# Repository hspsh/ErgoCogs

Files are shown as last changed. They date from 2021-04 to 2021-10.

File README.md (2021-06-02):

# ErgoCogs - modular ErgoDox for lifelong tinkerers

The idea for this project was born, when a couple of us couldn't decide on which features should our upcoming ErgoDox fork have.

The (conflicting) ideas were:
* Basic teensy with mini-usb
* Anything USB-C based
* Battery - powered bluetooth keyboard
* Custom STM32-based logic with SMD pre-assembly at factory

So why not have it all? The simplest solution is splitting the design into 2 parts. It has many advantages:

* The stupid matrix PCB is also the most expensive, as PCB manufacturers usually charge extra for anything larger than 10x10cm.
* If you get bored with with your basic bitch cherry mx matrix, why not swap it for them crunchy jade kalihs? Maybe just for a weekend? Or maybe sell your old matrix to a fellow hacker!
* The controller PCBs are small, and hence dirt cheap, and this is where most of customisation would take place. Take your time and experiment with wacky knobs and OLED displays until you get your perfect hackertyper experience.

It also has some disadvantages:

* The goldpin connector might be not the most relaiable way to connect 2PCBs. We're yet to check if this concept actually works out. Worst case, both sides may be semi-permanently soldered together with longer pinheaders.

## MatrixCog

This PCB is as dumb as it gets - it's basically an switch matrix routed do the 2x5 + 2x3 goldpin side connectors. It also features some LEDs.

To save some time, I recommend ordering this one with silicon diodes pre-assembled (`.cpl` file is included)

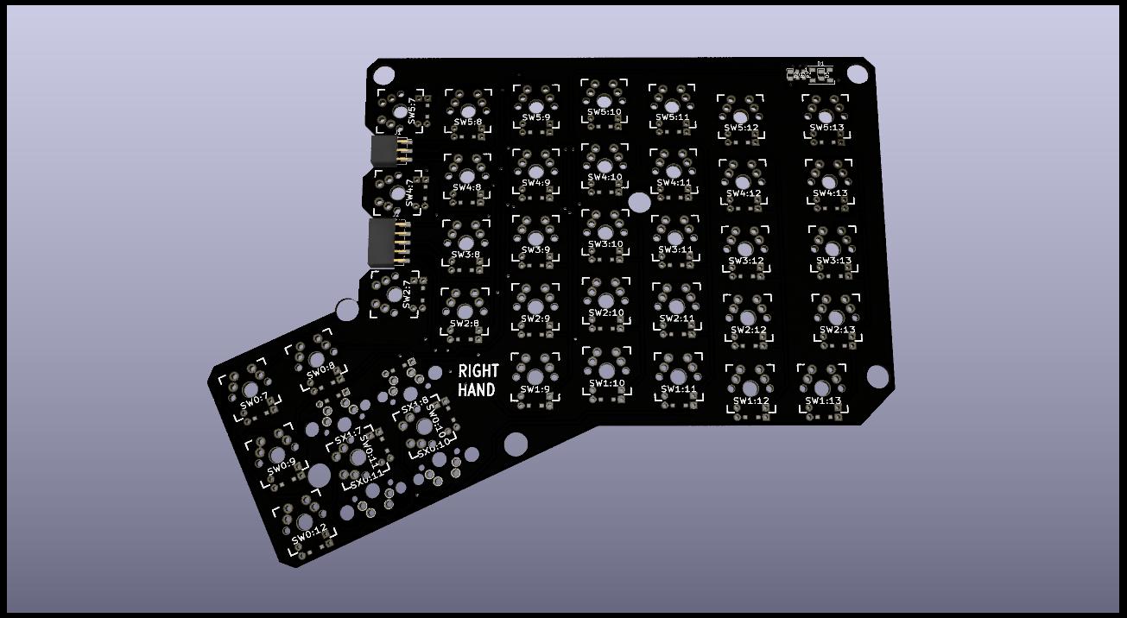
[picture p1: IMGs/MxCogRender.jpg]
Matrix Cog Render


## BrainCogs

Here's when the fun begins. We provide 2 example hemispheres that feature some basic functionalities. You can fork the shit out of this repo and modify these for your own needs.
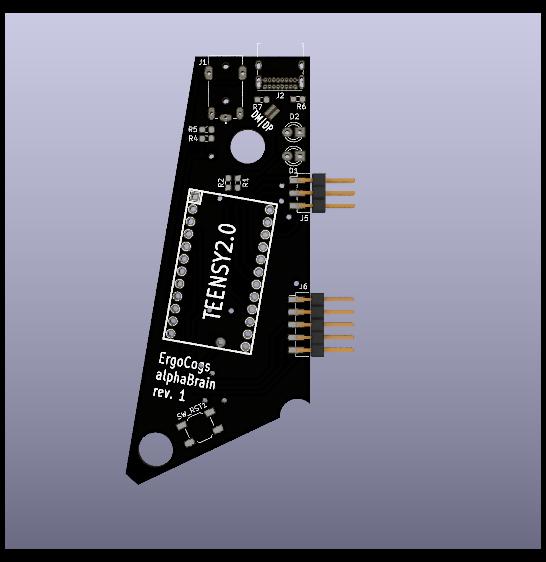
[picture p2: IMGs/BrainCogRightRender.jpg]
Brain Cog right hemisphere render

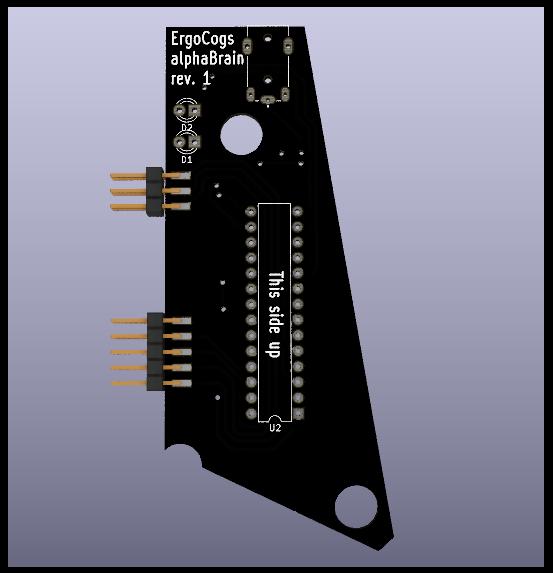
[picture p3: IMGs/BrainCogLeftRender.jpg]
Brain Cog left hemisphere render


## Some pictures

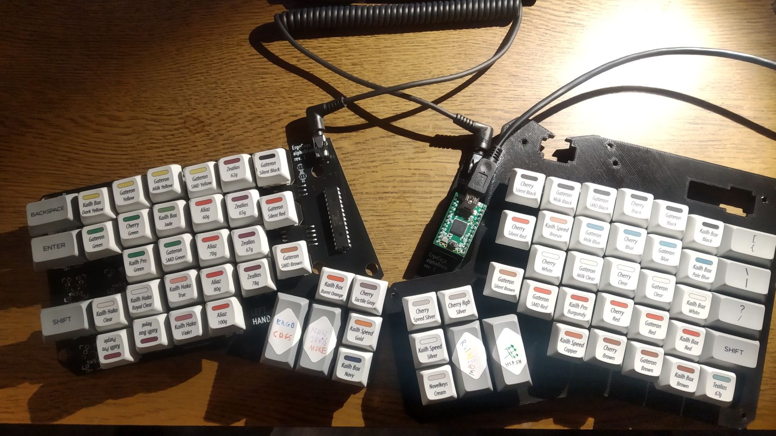
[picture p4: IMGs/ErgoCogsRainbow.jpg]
Prototype ErgoCogs keyboard with switches from a tester


More to come...

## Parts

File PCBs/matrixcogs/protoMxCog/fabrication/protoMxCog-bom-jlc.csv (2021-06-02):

Comment | Designator | Footprint | LCSC Part #
WS2812B RGB LED with integrated controller | D1,D4 | LED_WS2812B_PLCC4_5.0x5.0mm_P3.2mm
D | D1:7,D1:8 | DIODE
LED_R | D2,D3 | LED_0805_2012Metric_Pad1.15x1.40mm_HandSolder
LED_G | D5,D6 | LED_0805_2012Metric_Pad1.15x1.40mm_HandSolder
MECHANICAL | H99 | ErgoDOXmech
Conn_01x06 Generic connector, single row, 01x06, script generated (kicad-library-utils/schlib/autogen/connector/) | J1 | ErgoCogs_sidecon_top
Conn_01x10 Generic connector, single row, 01x10, script generated (kicad-library-utils/schlib/autogen/connector/) | J2 | ErgoCogs_sidecon_bot
470 Resistor, small symbol | R1,R2,R3,R4 | R_0603_1608Metric_Pad0.98x0.95mm_HandSolder
STAB200 | S1,S2 | STAB_PCB940
SW_DIODE | DS1,DS2,DS3,DS4,DS5,DS6,DS7,DS8,DS9,DS10,DS11,DS12,DS13,DS14,DS15,DS16,DS17,DS18,DS19,DS20,DS21,DS22,DS23,DS24,DS25,DS26,DS27,DS28,DS29,DS30,DS31,DS32,DS33,DS34,DS35,DS36,DS37,DS38,DS39,DS40,DS41,DS42 | SOD-123

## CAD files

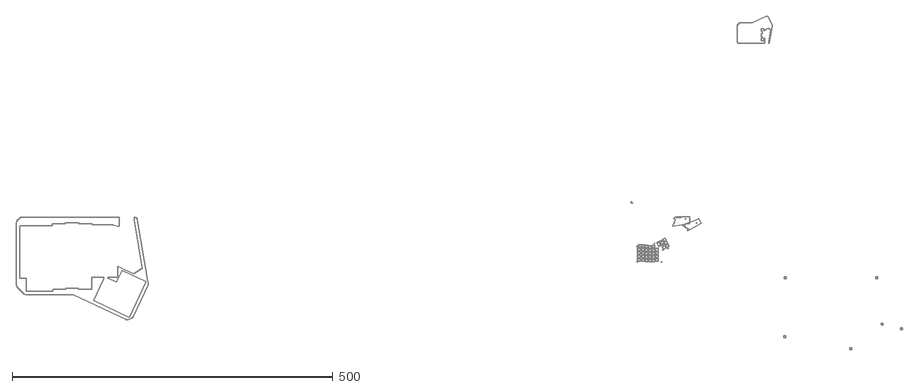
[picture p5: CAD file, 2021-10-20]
GearBoxes/ErgoCogs_integrated/integrated_plate_all.dxf
1380.8 x 520.0

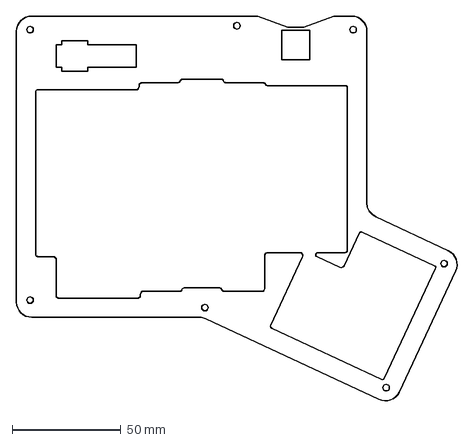
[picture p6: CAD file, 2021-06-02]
GearBoxes/ErgoDOX Acrylic Case - Designed by Litster/Standard/Left/ErgoDOX Case Layer 2 Spacer - Left.dxf
202.8 x 177.8 mm

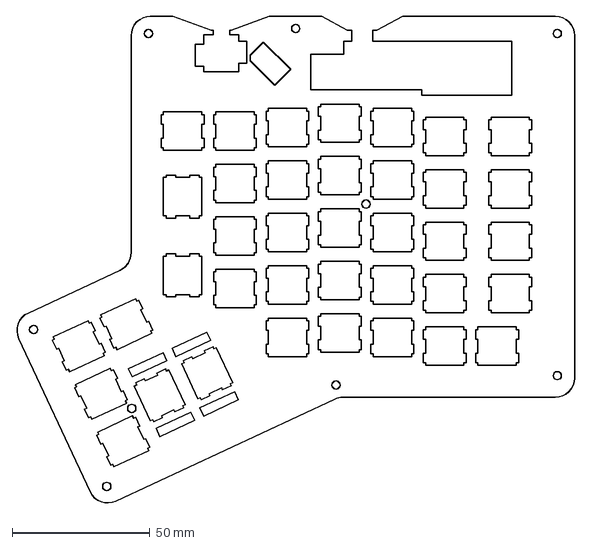
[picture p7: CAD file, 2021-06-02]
GearBoxes/ErgoDOX Acrylic Case - Designed by Litster/Standard/Right/ErgoDOX Case Layer 3 Plate - Right.dxf
202.8 x 177.8 mm

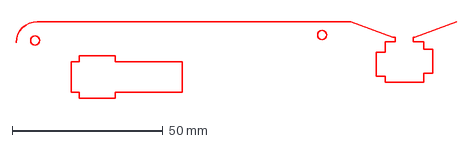
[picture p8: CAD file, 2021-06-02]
GearBoxes/ErgoDOX Acrylic Case - Designed by Litster/with Wrist Rest/Left/test cut.dxf
146.0 x 25.5 mm

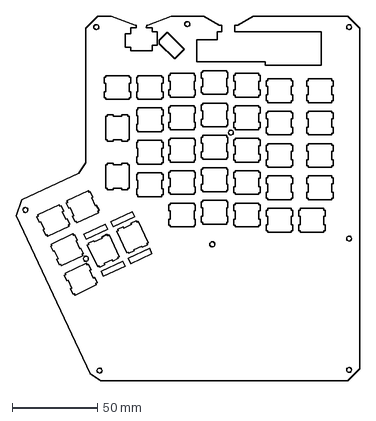
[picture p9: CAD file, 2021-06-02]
GearBoxes/ErgoDOX Acrylic Case - Designed by Litster/with Wrist Rest/Right/ErgoDOX Wrist Rest Case Layer 3 Plate - Right.dxf
202.0 x 214.1 mm

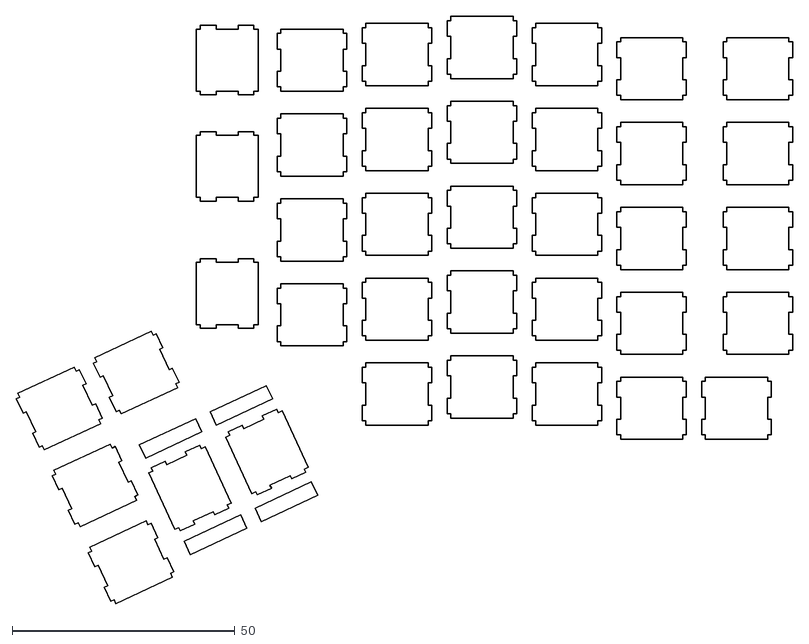
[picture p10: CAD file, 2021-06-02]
PCBs/matrixcogs/protoMxCog/fabrication/protoMxCog-Eco2_User.dxf
174.2 x 131.8

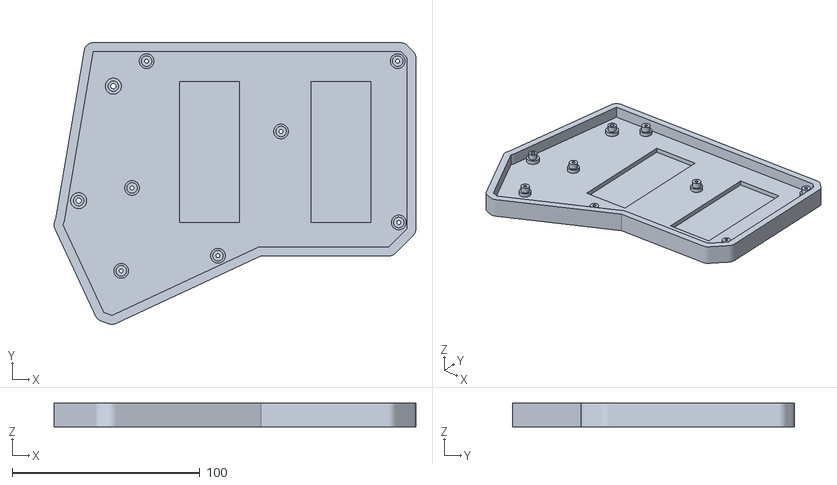
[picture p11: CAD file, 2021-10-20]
GearBoxes/ErgoCogs_integrated/integrated_plate.stl
192.8 x 150.1 x 12.6

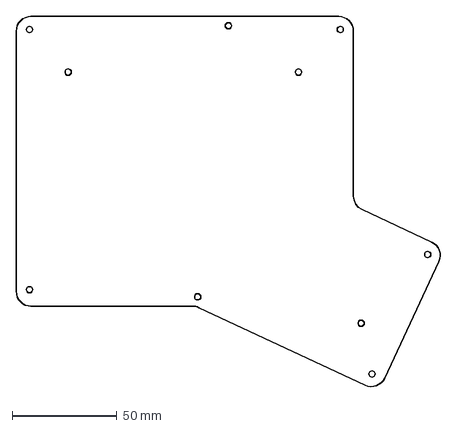
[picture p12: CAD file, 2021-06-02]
GearBoxes/ErgoDOX Acrylic Case - Designed by Litster/Standard/Left/ErgoDOX Case Layer 5 Bottom - Left.dxf
202.8 x 177.8 mm

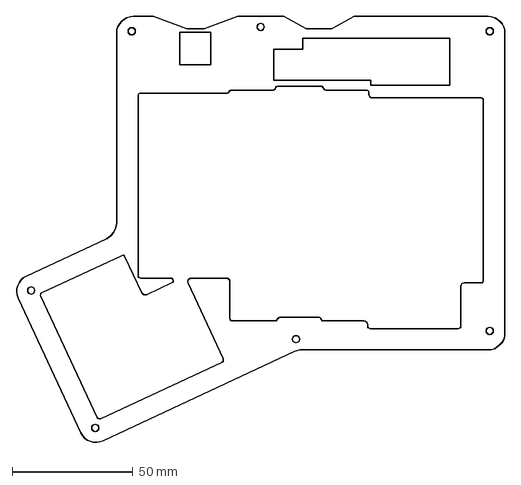
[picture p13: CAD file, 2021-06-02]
GearBoxes/ErgoDOX Acrylic Case - Designed by Litster/Standard/Right/ErgoDOX Case Layer 2 Spacer - Right.dxf
202.8 x 177.8 mm

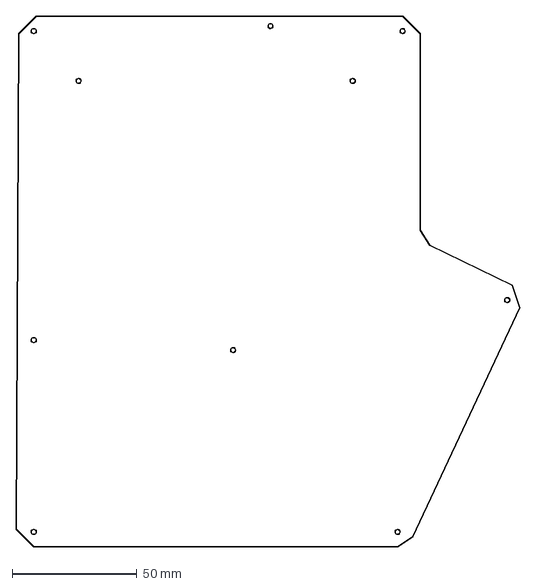
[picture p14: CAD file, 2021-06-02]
GearBoxes/ErgoDOX Acrylic Case - Designed by Litster/with Wrist Rest/Left/ErgoDOX Case Layer 5 Bottom - Left.dxf
202.0 x 213.0 mm

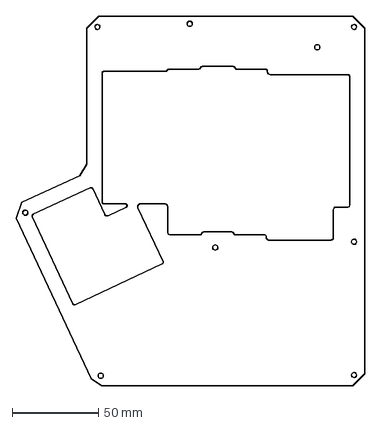
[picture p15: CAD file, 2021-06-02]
GearBoxes/ErgoDOX Acrylic Case - Designed by Litster/with Wrist Rest/Right/ErgoDOX Wrist Rest Case Layer 1 Top - Right.dxf
202.0 x 214.1 mm

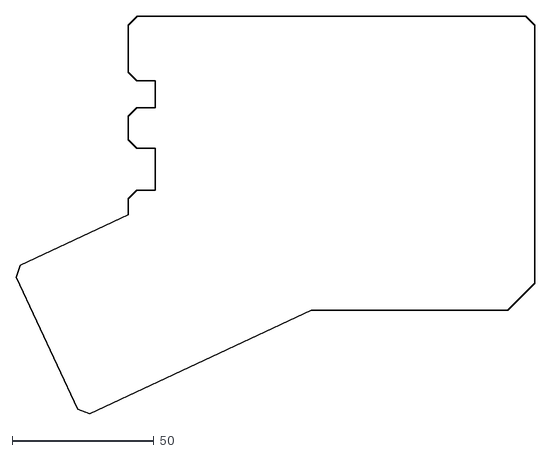
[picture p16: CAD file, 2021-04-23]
PCBs/matrixcogs/protoMxCog/fabrication/protoMxCog-Edge_Cuts.dxf
182.8 x 140.1

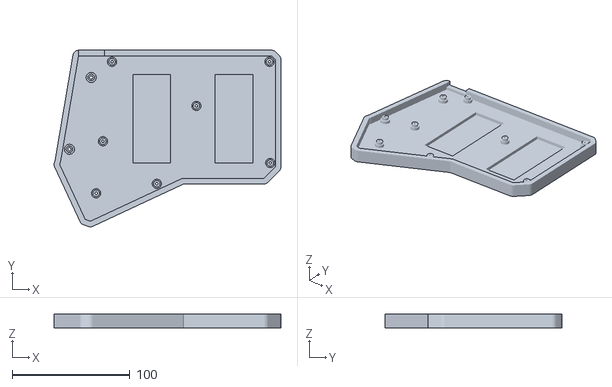
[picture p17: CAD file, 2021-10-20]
GearBoxes/ErgoCogs_integrated/integrated_plate_right.stl
192.8 x 150.1 x 11.6

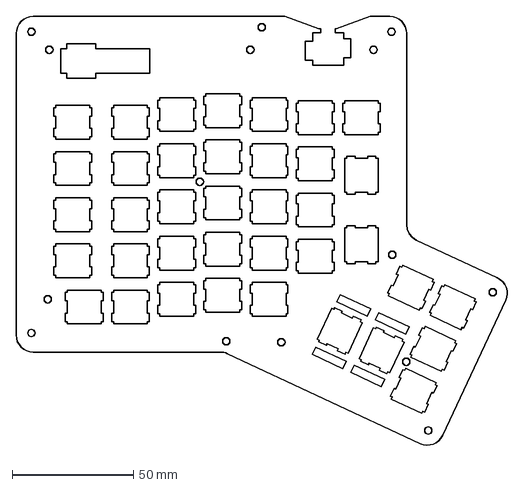
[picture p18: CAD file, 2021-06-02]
GearBoxes/ErgoDOX Acrylic Case - Designed by Litster/Standard/Left/ErgoDOX Case Layer 3 Plate - Left.dxf
202.8 x 177.8 mm

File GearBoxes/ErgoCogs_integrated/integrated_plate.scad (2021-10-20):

plate_h=1.55;
board_h=1.5;
bottom_h=5;
bottom_space=2.5;
side_h=5;

tolerance=0.2;
screw_d=2.3;


actual_hole_d=6;
jack_d=7;

fix_scale=1.0075; // The boards are a bit bigger? My priter uncalibrated ?

weight_h = 3;
weight_x = 32;
weight_y = 75;

$fn=30;

module tray(plate_h=plate_h,bottom_h=bottom_h,side_h=side_h,tolerance=tolerance,outline_file="outer_outline.dxf",sides=true,bottom_space=bottom_space) {

  in_offset = sides ? tolerance : bottom_h ;
  difference(){
    linear_extrude(bottom_h+side_h+plate_h)
      offset(r=bottom_h)
        import(outline_file);
    translate([0,0,bottom_h])
      linear_extrude(bottom_h+side_h+plate_h)
        offset(r=in_offset)
          import(outline_file);    
  }
}

module standoffs(plate_h=plate_h,bottom_h=bottom_h,side_h=side_h,tolerance=tolerance, 
    holes_file="mount_holes.dxf")
{
    linear_extrude(bottom_h+side_h)
        offset(delta=-tolerance/2)
          import(holes_file); // "columns"
    linear_extrude(bottom_h+bottom_space)
        offset(delta=1)
          import(holes_file); // plate rests
}

module holes(
    plate_h=plate_h,
    bottom_h=bottom_h,
    side_h=side_h,
    tolerance=tolerance, 
    delta=-0.4,
    holes_file="mount_holes.dxf")
{
    linear_extrude(bottom_h+side_h+1)
      offset(delta=-(actual_hole_d-screw_d)/2)
        import(holes_file); // screw holes
    linear_extrude(bottom_h)
      offset(delta=delta)
        import(holes_file); // nut hole
}

module bottom(plate_h=plate_h,bottom_h=bottom_h,side_h=side_h,tolerance=tolerance,outline_file="outer_outline.dxf",holes_file="mount_holes.dxf",sides=true,bottom_space=bottom_space) 
{
  brain_offset = [-88.79,-5.7,0];
  difference(){
    union(){
      tray(plate_h,bottom_h=bottom_h,side_h=side_h,tolerance=tolerance,outline_file=outline_file,sides=sides,bottom_space=bottom_space);
      standoffs(plate_h=plate_h,bottom_h=bottom_h,side_h=side_h,tolerance=tolerance, holes_file=holes_file);
      translate(brain_offset) standoffs(plate_h=plate_h,bottom_h=bottom_h,side_h=side_h,tolerance=1, holes_file="brain_holes.dxf");
    }
    holes(plate_h=plate_h,bottom_h=bottom_h,side_h=side_h,tolerance=tolerance, holes_file=holes_file);
    translate(brain_offset) holes(plate_h=plate_h,bottom_h=bottom_h,side_h=side_h, holes_file="brain_holes.dxf");
    // weight slots
    translate([85, -140, bottom_h-weight_h]) cube([weight_x,weight_y,weight_h]);
    translate([155, -140, bottom_h-weight_h]) cube([weight_x,weight_y,weight_h]);
    
    // IO
    translate([39,-60,bottom_h+bottom_space +0])
        cube([22,22,20]);

  }
}


module brain_translate(){
  translate([-88.79,-5.7,0])
    children();
}

module brain_bottom(plate_h=plate_h,bottom_h=bottom_h,side_h=side_h,tolerance=tolerance,outline_file="brain_outline.dxf",holes_file="brain_holes.dxf",sides=true,bottom_space=bottom_space)
{
  brain_translate()
    bottom(plate_h=plate_h,bottom_h=bottom_h,side_h=side_h,tolerance=tolerance,outline_file=outline_file,holes_file=holes_file,sides=sides,bottom_space=bottom_space);
}

module full_bottom(plate_h=plate_h,bottom_h=bottom_h,side_h=side_h,tolerance=tolerance){
//  union(){
//    difference(){
      bottom(plate_h=plate_h,bottom_h=bottom_h,side_h=side_h,tolerance=tolerance);
//      brain_translate()
//        linear_extrude(side_h+2*bottom_h+bottom_space)
//          import("brain_bigger_outline.dxf");
//    }
//  }
}

module plate(plate_h=plate_h) {
  linear_extrude(plate_h)
    import("plate_outline.dxf");
}

module cutouts(plate_h=plate_h) {
linear_extrude(plate_h)
  union(){
    import("plate_cutouts.dxf");  
    // For M3 - check if screw head fits!
    //offset(r=-1.45)
    // For M2.5
    offset(r=-1.67)
    // For M2
    //offset(r=-1.86)
      import("mount_holes.dxf");
  }
}

module plate_with_cutouts(plate_h=plate_h){
  difference(){
    plate(plate_h);
    cutouts(plate_h);
  }
}

module plate_sample(plate_h=plate_h){
  intersection(){
    union(){
      translate([40,-195,0])
        rotate([0,0,25])
          cube([65,42,plate_h]);
      translate([81,-169.5,0])
        cube([130,40,plate_h]);
    }

    plate_with_cutouts(plate_h);
  }
}

module brain_bottom_cartridge(usb=false) {
  slider_w=2;
  slider_l=9;
  slider_gap=0.1;
  difference(){
    union(){
      intersection(){
        brain_bottom();
        brain_translate()
          linear_extrude(side_h+2*bottom_h+bottom_space)
            import("brain_bigger_outline.dxf");
      }
      translate([60,-49-slider_w,bottom_h])
        cube([slider_l,slider_w,bottom_space-tolerance]); // slider rail
    }
    linear_extrude(10)
      offset(delta=1.2)
        import("mount_holes.dxf");
    if(usb)
      translate([40,-80,bottom_h+bottom_space+board_h+0.5])
        cube([20,20,20]);
    translate([41.5,-47.15,bottom_h+side_h-0.5])
      translate([jack_d/2,0,0])
        rotate([90,0,0])
        union(){
          translate([-jack_d/2,0,0])
            cube([jack_d,jack_d,bottom_h]);
          if(usb)
            translate([jack_d/2+2,-jack_d/2+1,0])
              cube([10,10,bottom_h]);
          cylinder(d=jack_d,h=bottom_h);
        }
  }  
}
module all(plate=false,bottom=false,brain=false, right=false, left=false){
  scale([fix_scale,fix_scale,fix_scale]){
      
    if(left){
      if(bottom)
        translate([20,0,0])
          full_bottom();
      if(brain)
        translate([0,0,0])
          brain_bottom_cartridge(usb=true);
      if(plate)
        translate([0,-160,0])
          //sample();
          plate_with_cutouts();

    }
    if(right || !right && !left) // right hand by default
      mirror([1,0,0]){
        if(bottom)
          translate([20,0,0])
            full_bottom();
        if(brain)
          translate([0,0,0])
            brain_bottom_cartridge(usb=false);
        if(plate)
          translate([0,-160,0])
            //sample();
            plate_with_cutouts();

      }  
  }
}

//all(brain=false,bottom=true,plate=false,left=true,right=true);

bottom();

//plate_sample();
//all(bottom=true,left=true,right=true);

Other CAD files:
GearBoxes/ErgoDOX Acrylic Case - Designed by Litster/Standard/Right/ErgoDOX Case Layer 4 Spacer - Right.dxf
GearBoxes/ErgoDOX Acrylic Case - Designed by Litster/with Wrist Rest/Left/ErgoDOX Case Layer 4 Spacer - Left.dxf
GearBoxes/ErgoDOX Acrylic Case - Designed by Litster/with Wrist Rest/Right/ErgoDOX Wrist Rest Case Layer 2 Spacer - Right.dxf
GearBoxes/ErgoCogs_integrated/plate.stl
GearBoxes/ErgoCogs_integrated/plate.scad
GearBoxes/ErgoCogs_integrated/all.stl
GearBoxes/ErgoCogs_integrated/bottom.stl
GearBoxes/ErgoCogs_integrated/brain_bigger_outline.dxf
GearBoxes/ErgoCogs_integrated/brain_bottom.stl
GearBoxes/ErgoCogs_integrated/brain_holes.dxf
GearBoxes/ErgoCogs_integrated/brain_outline.dxf
GearBoxes/ErgoCogs_integrated/mount_holes.dxf
GearBoxes/ErgoCogs_integrated/outer_outline.dxf
GearBoxes/ErgoCogs_integrated/plate_cutouts.dxf
GearBoxes/ErgoCogs_integrated/plate_outline.dxf
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

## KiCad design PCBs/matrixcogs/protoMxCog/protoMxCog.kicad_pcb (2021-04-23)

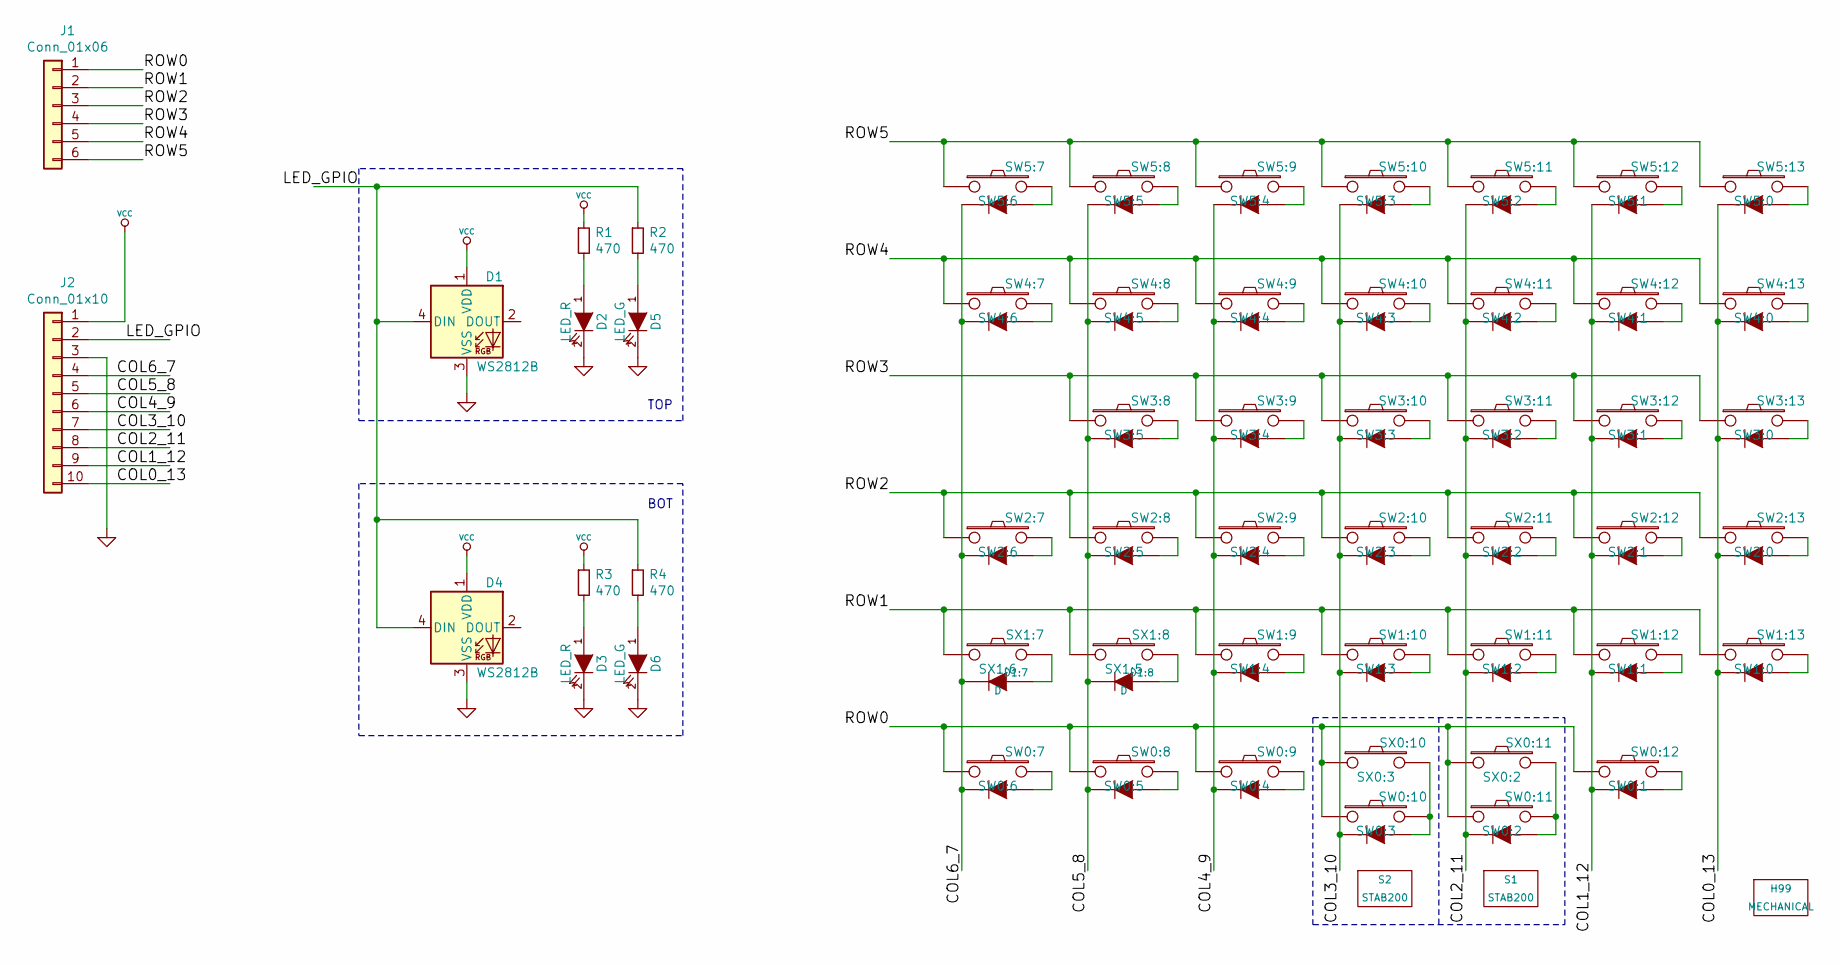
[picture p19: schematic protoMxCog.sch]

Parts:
D1, D4: WS2812B; LED_WS2812B_PLCC4_5.0x5.0mm_P3.2mm
D1:7, D1:8: D; DIODE
D2, D3: LED_R; LED_0805_2012Metric_Pad1.15x1.40mm_HandSolder
D5, D6: LED_G; LED_0805_2012Metric_Pad1.15x1.40mm_HandSolder
H99: MECHANICAL; ErgoDOXmech
J1: Conn_01x06; ErgoCogs_sidecon_top
J2: Conn_01x10; ErgoCogs_sidecon_bot
R1, R2, R3, R4: 470; R_0603_1608Metric_Pad0.98x0.95mm_HandSolder
S1, S2: STAB200; STAB_PCB940
SW0:7: SW0:6; MX_FLIP_DIODE
SW0:8: SW0:5; MX_FLIP_DIODE
SW0:9: SW0:4; MX_FLIP_DIODE
SW0:10: SW0:3; MX_FLIP_DIODE
SW0:11: SW0:2; MX_FLIP_DIODE
SW0:12: SW0:1; MX_FLIP_DIODE
SW1:9: SW1:4; MX_FLIP_DIODE
SW1:10: SW1:3; MX_FLIP_DIODE
SW1:11: SW1:2; MX_FLIP_DIODE
SW1:12: SW1:1; MX_FLIP_DIODE
SW1:13: SW1:0; MX_FLIP_DIODE
SW2:7: SW2:6; MX_FLIP_DIODE
SW2:8: SW2:5; MX_FLIP_DIODE
SW2:9: SW2:4; MX_FLIP_DIODE
SW2:10: SW2:3; MX_FLIP_DIODE
SW2:11: SW2:2; MX_FLIP_DIODE
SW2:12: SW2:1; MX_FLIP_DIODE
SW2:13: SW2:0; MX_FLIP_DIODE
SW3:8: SW3:5; MX_FLIP_DIODE
SW3:9: SW3:4; MX_FLIP_DIODE
SW3:10: SW3:3; MX_FLIP_DIODE
SW3:11: SW3:2; MX_FLIP_DIODE
SW3:12: SW3:1; MX_FLIP_DIODE
SW3:13: SW3:0; MX_FLIP_DIODE
SW4:7: SW4:6; MX_FLIP_DIODE
SW4:8: SW4:5; MX_FLIP_DIODE
SW4:9: SW4:4; MX_FLIP_DIODE
SW4:10: SW4:3; MX_FLIP_DIODE
SW4:11: SW4:2; MX_FLIP_DIODE
SW4:12: SW4:1; MX_FLIP_DIODE
SW4:13: SW4:0; MX_FLIP_DIODE
SW5:7: SW5:6; MX_FLIP_DIODE
SW5:8: SW5:5; MX_FLIP_DIODE
SW5:9: SW5:4; MX_FLIP_DIODE
SW5:10: SW5:3; MX_FLIP_DIODE
SW5:11: SW5:2; MX_FLIP_DIODE
SW5:12: SW5:1; MX_FLIP_DIODE
SW5:13: SW5:0; MX_FLIP_DIODE
SX0:10: SX0:3; MX_FLIP
SX0:11: SX0:2; MX_FLIP
SX1:7: SX1:6; MX_FLIP
SX1:8: SX1:5; MX_FLIP

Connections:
/COL0_13: J2.10, SW1:13.4 (K), SW2:13.4 (K), SW3:13.4 (K), SW4:13.4 (K), SW5:13.4 (K)
/COL1_12: J2.9, SW0:12.4 (K), SW1:12.4 (K), SW2:12.4 (K), SW3:12.4 (K), SW4:12.4 (K), SW5:12.4 (K)
/COL2_11: J2.8, SW0:11.4 (K), SW1:11.4 (K), SW2:11.4 (K), SW3:11.4 (K), SW4:11.4 (K), SW5:11.4 (K)
/COL3_10: J2.7, SW0:10.4 (K), SW1:10.4 (K), SW2:10.4 (K), SW3:10.4 (K), SW4:10.4 (K), SW5:10.4 (K)
/COL4_9: J2.6, SW0:9.4 (K), SW1:9.4 (K), SW2:9.4 (K), SW3:9.4 (K), SW4:9.4 (K), SW5:9.4 (K)
/COL5_8: D1:8.2 (K), J2.5, SW0:8.4 (K), SW2:8.4 (K), SW3:8.4 (K), SW4:8.4 (K), SW5:8.4 (K)
/COL6_7: D1:7.2 (K), J2.4, SW0:7.4 (K), SW2:7.4 (K), SW4:7.4 (K), SW5:7.4 (K)
/LED_GPIO: D1.4 (DIN), D4.4 (DIN), J2.2, R2.1, R4.1
/ROW0: J1.1, SW0:7.1, SW0:8.1, SW0:9.1, SW0:10.1, SW0:11.1, SW0:12.1, SX0:10.1, SX0:11.1
/ROW1: J1.2, SW1:9.1, SW1:10.1, SW1:11.1, SW1:12.1, SW1:13.1, SX1:7.1, SX1:8.1
/ROW2: J1.3, SW2:7.1, SW2:8.1, SW2:9.1, SW2:10.1, SW2:11.1, SW2:12.1, SW2:13.1
/ROW3: J1.4, SW3:8.1, SW3:9.1, SW3:10.1, SW3:11.1, SW3:12.1, SW3:13.1
/ROW4: J1.5, SW4:7.1, SW4:8.1, SW4:9.1, SW4:10.1, SW4:11.1, SW4:12.1, SW4:13.1
/ROW5: J1.6, SW5:7.1, SW5:8.1, SW5:9.1, SW5:10.1, SW5:11.1, SW5:12.1, SW5:13.1
GND: D1.3 (VSS), D2.2 (K), D3.2 (K), D4.3 (VSS), D5.2 (K), D6.2 (K), J2.3, SW0:7.0 (GND), SW0:8.0 (GND), SW0:9.0 (GND), SW0:10.0 (GND), SW0:11.0 (GND), SW0:12.0 (GND), SW1:9.0 (GND), SW1:10.0 (GND), SW1:11.0 (GND), SW1:12.0 (GND), SW1:13.0 (GND), SW2:7.0 (GND), SW2:8.0 (GND), SW2:9.0 (GND), SW2:10.0 (GND), SW2:11.0 (GND), SW2:12.0 (GND), SW2:13.0 (GND), SW3:8.0 (GND), SW3:9.0 (GND), SW3:10.0 (GND), SW3:11.0 (GND), SW3:12.0 (GND), SW3:13.0 (GND), SW4:7.0 (GND), SW4:8.0 (GND), SW4:9.0 (GND), SW4:10.0 (GND), SW4:11.0 (GND), SW4:12.0 (GND), SW4:13.0 (GND), SW5:7.0 (GND), SW5:8.0 (GND), SW5:9.0 (GND), SW5:10.0 (GND), SW5:11.0 (GND), SW5:12.0 (GND), SW5:13.0 (GND)
unnamed: D1:7.1 (A), SX1:7.2
unnamed: D1:8.1 (A), SX1:8.2
unnamed: D2.1 (A), R1.2
unnamed: D3.1 (A), R3.2
unnamed: D5.1 (A), R2.2
unnamed: D6.1 (A), R4.2
unnamed: SW0:7.2, SW0:7.3 (A)
unnamed: SW0:8.2, SW0:8.3 (A)
unnamed: SW0:9.2, SW0:9.3 (A)
unnamed: SW0:10.2, SW0:10.3 (A), SX0:10.2
unnamed: SW0:11.2, SW0:11.3 (A), SX0:11.2
unnamed: SW0:12.2, SW0:12.3 (A)
unnamed: SW1:9.2, SW1:9.3 (A)
unnamed: SW1:10.2, SW1:10.3 (A)
unnamed: SW1:11.2, SW1:11.3 (A)
unnamed: SW1:12.2, SW1:12.3 (A)
unnamed: SW1:13.2, SW1:13.3 (A)
unnamed: SW2:7.2, SW2:7.3 (A)
unnamed: SW2:8.2, SW2:8.3 (A)
unnamed: SW2:9.2, SW2:9.3 (A)
unnamed: SW2:10.2, SW2:10.3 (A)
unnamed: SW2:11.2, SW2:11.3 (A)
unnamed: SW2:12.2, SW2:12.3 (A)
unnamed: SW2:13.2, SW2:13.3 (A)
unnamed: SW3:8.2, SW3:8.3 (A)
unnamed: SW3:9.2, SW3:9.3 (A)
unnamed: SW3:10.2, SW3:10.3 (A)
unnamed: SW3:11.2, SW3:11.3 (A)
unnamed: SW3:12.2, SW3:12.3 (A)
unnamed: SW3:13.2, SW3:13.3 (A)
unnamed: SW4:7.2, SW4:7.3 (A)
unnamed: SW4:8.2, SW4:8.3 (A)
unnamed: SW4:9.2, SW4:9.3 (A)
unnamed: SW4:10.2, SW4:10.3 (A)
unnamed: SW4:11.2, SW4:11.3 (A)
unnamed: SW4:12.2, SW4:12.3 (A)
unnamed: SW4:13.2, SW4:13.3 (A)
unnamed: SW5:7.2, SW5:7.3 (A)
unnamed: SW5:8.2, SW5:8.3 (A)
unnamed: SW5:9.2, SW5:9.3 (A)
unnamed: SW5:10.2, SW5:10.3 (A)
unnamed: SW5:11.2, SW5:11.3 (A)
unnamed: SW5:12.2, SW5:12.3 (A)
unnamed: SW5:13.2, SW5:13.3 (A)
VCC: D1.1 (VDD), D4.1 (VDD), J2.1, R1.1, R3.1

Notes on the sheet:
TOP
BOT

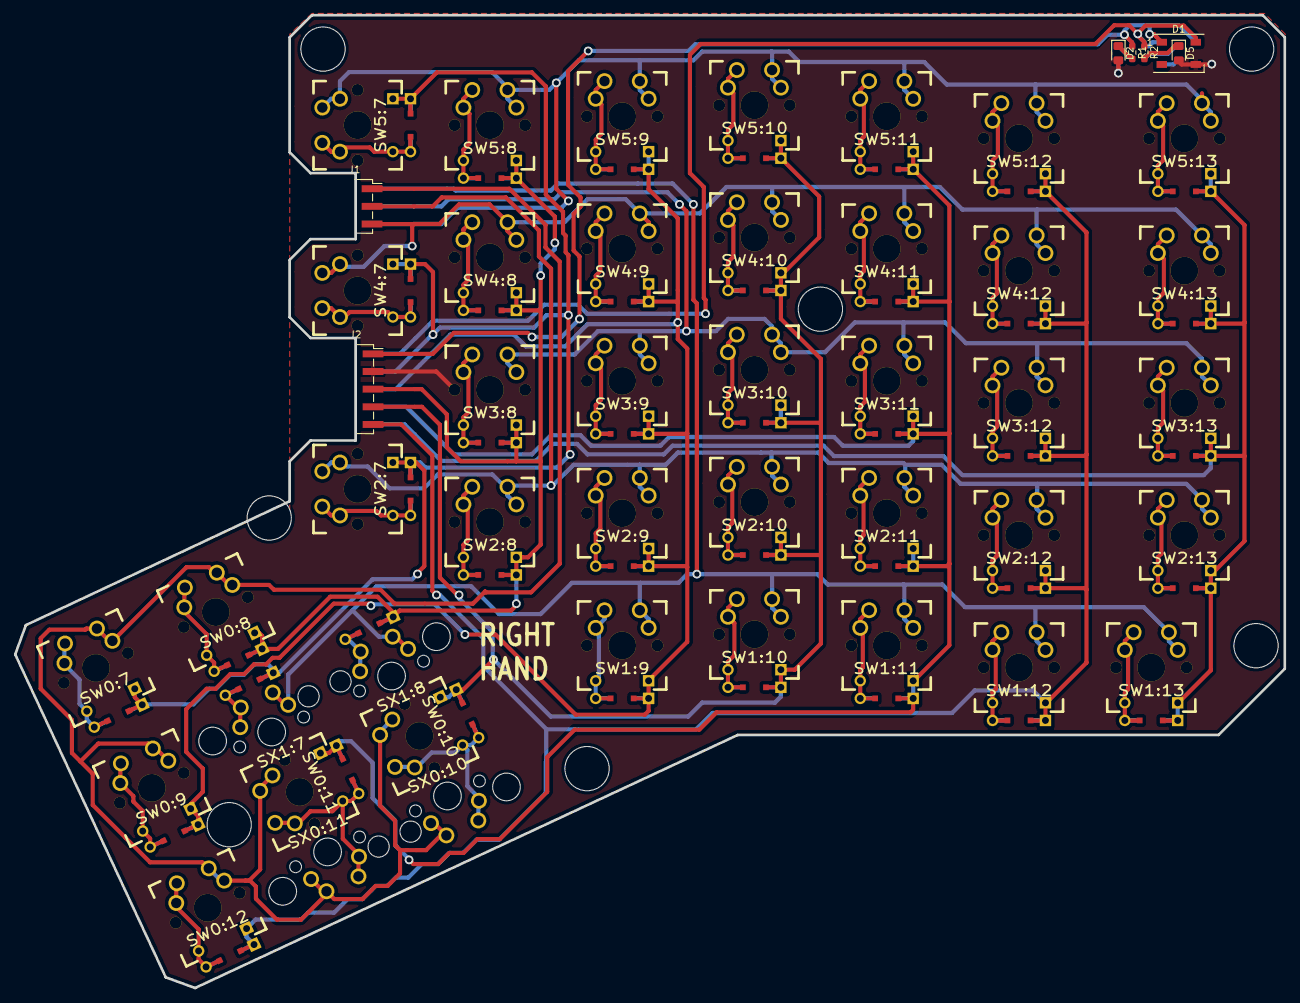
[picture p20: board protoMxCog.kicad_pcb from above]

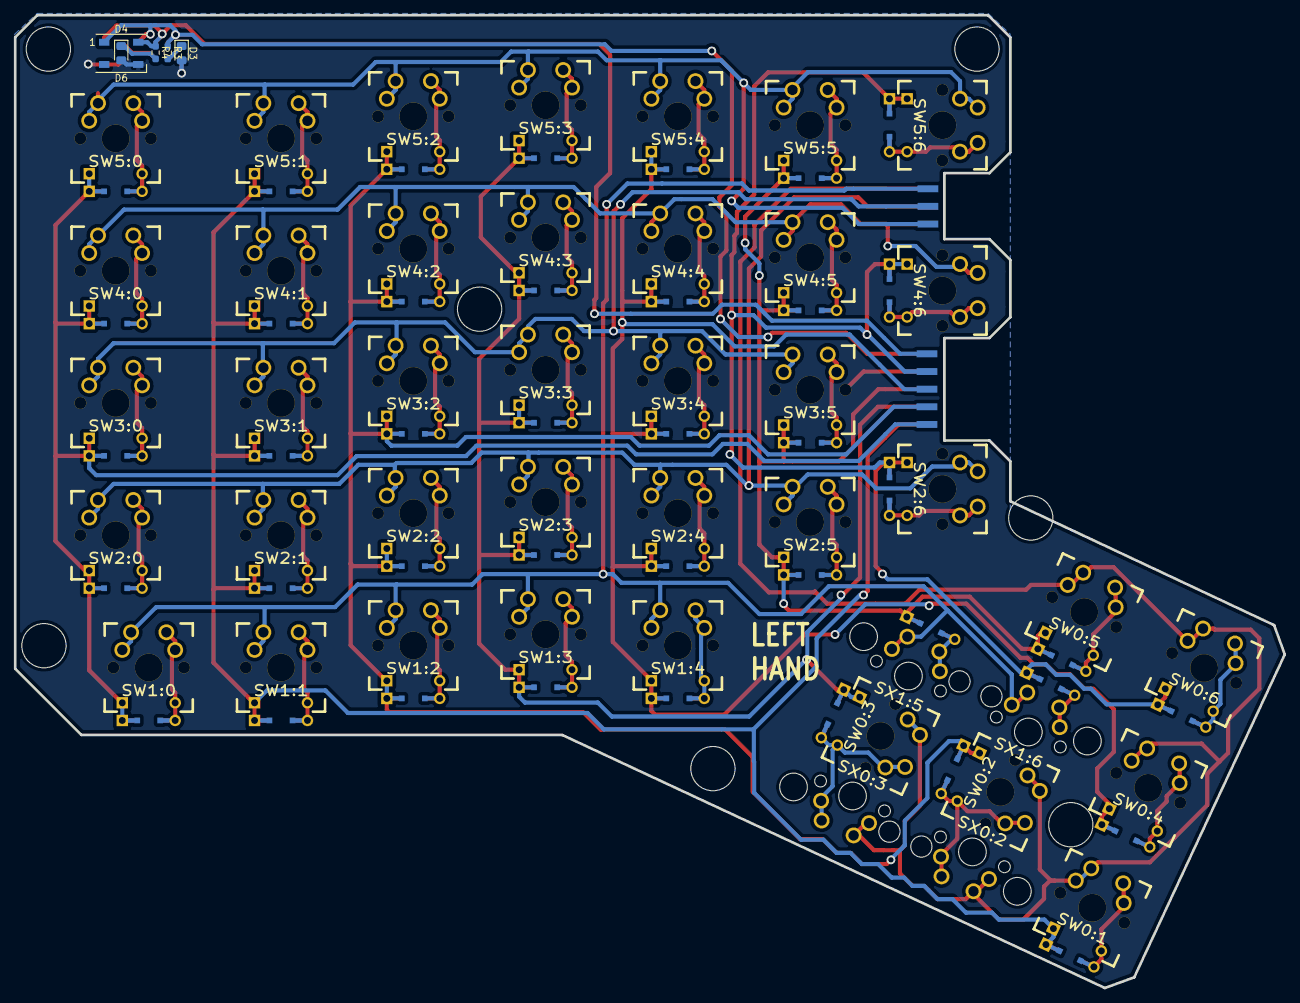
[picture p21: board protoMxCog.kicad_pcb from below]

Board: 2 copper layers, 182.8 x 140.1 mm, 59 parts (5 on the bottom side), 60 nets.

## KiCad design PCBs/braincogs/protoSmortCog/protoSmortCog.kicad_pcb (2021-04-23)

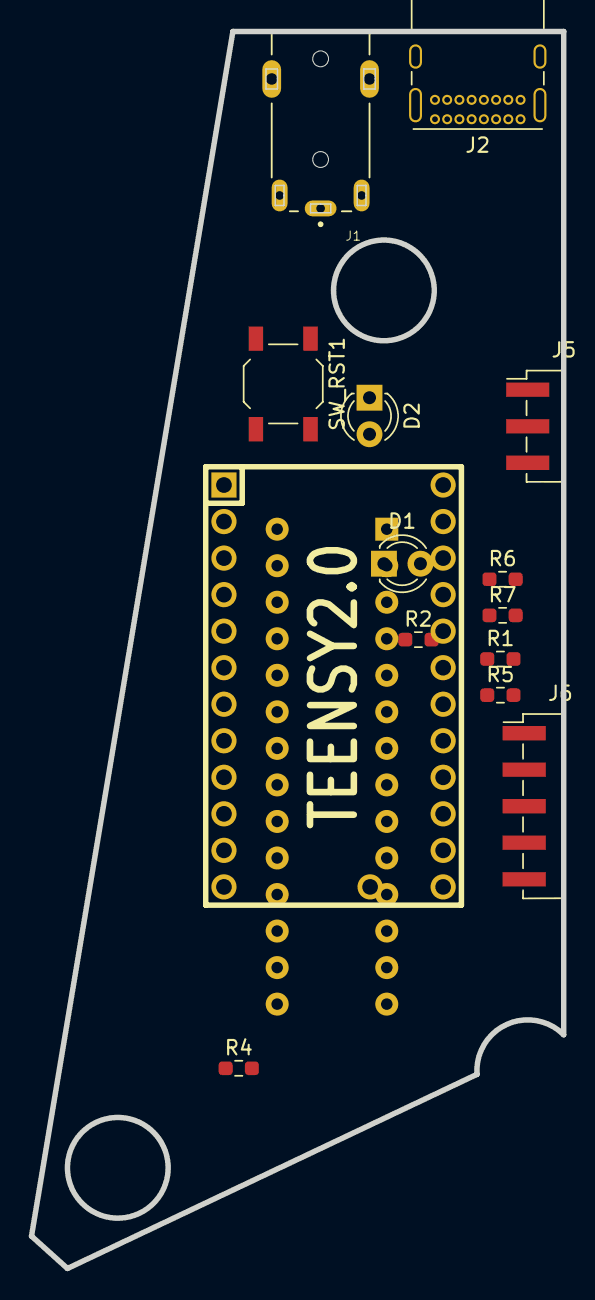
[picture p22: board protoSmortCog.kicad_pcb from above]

Board: 2 copper layers, 37.0 x 86.0 mm, 15 parts (1 on the bottom side), 28 nets, no tracks yet.

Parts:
D1, D2: LED; LED_D3.0mm_Clear
J1: AudioJack4; CLIFF_FC68125
J2: USB_C_Receptacle_USB2.0; USB_C_Receptacle_GCT_USB4085
J5: Conn_01x06; ErgoCogs_sidecon_brain_top
J6: Conn_01x10; ErgoCogs_sidecon_brain_bot
R1, R2, R4, R5, R6, R7: 4k7; R_0603_1608Metric_Pad0.98x0.95mm_HandSolder
SW_RST1: SWITCH_PUSH; SW_SPST_TL3342
U1: TEENSY2.0; TEENSY_2.0_WITH_RESET
U2: MCP23018; DIP-28_W7.62mm

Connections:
/COL0_13: J6.10, U2.20
/COL1_12: J6.9, U2.21
/COL2_11: J6.8, U2.22
/COL3_10: J6.7, U2.23
/COL4_9: J6.6, U2.24
/COL5_8: J6.5, U2.25
/COL6_7: J6.4, U2.26
/LED_A: R1.1, U1.21, U2.10
/LED_B: R2.1, U1.22, U2.9
/LED_GPIO: J6.2, U1.6
/ROW0: J5.1, U1.23, U2.8
/ROW1: J5.2, U1.24, U2.7
/ROW2: J5.3, U1.25, U2.6
/ROW3: J5.4, U1.26, U2.5
/ROW4: J5.5, U1.27, U2.4
/ROW5: J5.6, U1.28, U2.3
/RST: SW_RST1.1, U1.16
/SCL: J1.R1, R4.2, U1.7, U2.12
/SDA: J1.T, R5.2, U1.8, U2.13
GND: D1.1, D2.1, J1.S, J2.A1, J2.A12, J2.B1, J2.B12, J2.S1, J6.3, R6.2, R7.2, SW_RST1.2, U1.1, U1.18, U2.1, U2.15
unnamed: D1.2, R1.2
unnamed: D2.2, R2.2
unnamed: J2.A5, R6.1
unnamed: J2.A6, J2.B6
unnamed: J2.A7, J2.B7
unnamed: J2.B5, R7.1
VBUS: J2.A4, J2.A9, J2.B4, J2.B9
VCC: J1.R2, J6.1, R4.1, R5.1, U1.20, U1.29, U2.11, U2.16

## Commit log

2021-02-15 adding cringe
    [ErgoDOX.kicad_pcb]
2021-02-15 uncscronching the original repo state
    [ErgoDOX-B.Mask.gbs, ErgoDOX-B.Paste.gbp, ErgoDOX-B.SilkS.gbo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]
2021-02-15 Creating proper directory structure, splitting pcb project into 2 independent projects
    [ErgoDOX.kicad_pcb, ErgoDOX.sch]
2021-02-15 removing original project files
    [ErgoDOX.kicad_pcb, ErgoDOX.sch]
2021-02-23 removing top part of PCB on switch matrix board
    [ErgoDOX.kicad_pcb, ErgoDOX.sch]
2021-03-16 refactoring library structure, finishing basic matrix cog
    [ErgoDOX.kicad_pcb, ErgoDOX.sch]
2021-03-21 renaming projects
    [protoMxCog.kicad_pcb, protoMxCog.sch, protoSmortCog.kicad_pcb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]
2021-03-21 adjusting former ergodox project for a smart cog template (WIP)
    [protoSmortCog.kicad_pcb, protoSmortCog.sch]
2021-04-23 1st version of braincogs
    [alphaLeftHemi.kicad_pcb, alphaLeftHemi.sch, alphaRightHemi.kicad_pcb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]
2021-06-02 repo cleanup, adding fab files for PCBs
    [alphaLeftHemi.kicad_pcb, alphaRightHemi.kicad_pcb, protoMxCog-Eco2_User.dxf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]
2021-06-02 removing spaces from folder names, adding example photo
    [ErgoDOX Case Layer 1 Top - Left.dxf, ErgoDOX Case Layer 1 Top - Right.dxf, ErgoDOX Case Layer 2 Spacer - Left.dxf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]
2021-06-09 Switch mount plate
    [outer_outline.dxf, plate.scad, plate.stl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]
2021-06-14 Case alpha
    [all.stl, bottom.stl, brain_bigger_outline.dxf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]
